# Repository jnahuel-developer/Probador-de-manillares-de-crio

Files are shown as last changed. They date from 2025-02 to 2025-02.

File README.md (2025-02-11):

# 🛠️ Probador de Manillares de Crio  

Dispositivo para probar y validar el correcto funcionamiento de manillares para la terapia de Crio Radio Frecuencia.  
Este repositorio incluye tanto el firmware para el microcontrolador como el diseño del PCB.  

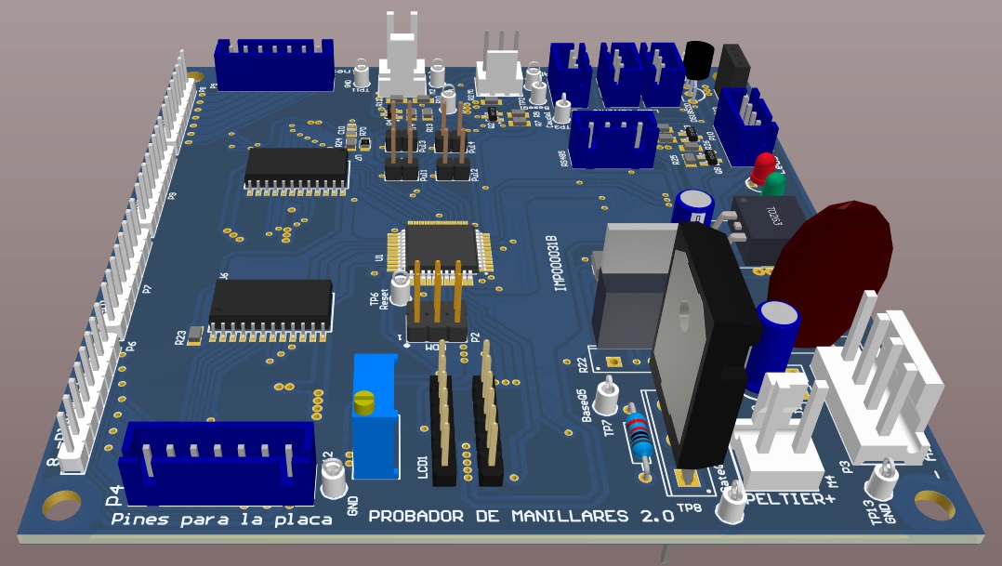
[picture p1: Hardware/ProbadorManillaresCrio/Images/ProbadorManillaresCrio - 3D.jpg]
Vista 3D del PCB
  

---
---

## ❄️ Manillar para la terapia de Crio Radio Frecuencia  

El manillar para la terapia de Crio Radio Frecuencia combina un sistema de refrigeración con un arreglo de terminales para la emisión de RF.  

### 🔹 **Sistema de Refrigeración**  
El sistema de refrigeración incluye una celda Peltier, encargada de disminuir la temperatura sobre los pernos hasta -15°C. Para disipar el calor generado, cuenta con un circuito cerrado de circulación de agua que lo transporta fuera del manillar.  

Para gestionar este proceso, el **Probador** integra:  
- Circuitos independientes de activación de una **bomba de agua de 12V** y un **cooler** de refrigeración del agua.  
- Un **caudalímetro**, que verifica la correcta circulación del flujo de agua.  
- Un **sensor DS18S10**, ubicado en el ingreso de la bomba, que monitorea la temperatura y previene condiciones inseguras.  
- Un **circuito de alimentación de potencia** para la celda Peltier, con una medición de la corriente consumida mediante una **resistencia Shunt**.  
- **Dos sensores DS18S10** adicionales, que registran la temperatura en ambas caras de la celda.  

### 🔹 **Emisión de RF**  
Para la verificación de la emisión de radiofrecuencia, el **Probador** emplea dos **multiplexores analógicos de 16 canales**, los cuales permiten inyectar señales y medir la continuidad de los circuitos. Esto posibilita no solo verificar que los pernos tengan continuidad, sino también que estén correctamente ubicados.  

### 🔹 **Interfaz y Control**  
El **Probador** se maneja mediante un sistema de **cuatro pulsadores** y una **pantalla LCD**, que guían al operador durante el proceso de prueba del manillar.  

Este sistema permite realizar un test completo de cada unidad de manera rápida y eficiente, asegurando su correcto funcionamiento sin necesidad de recurrir a equipos comerciales.

---
---

## 📁 Contenido del Repositorio  

📂 **Probador-de-manillares-de-crio/**  
├── 📁 **firmware/** → Código fuente para el microcontrolador  
├── 📁 **hardware/** → Diseño del PCB, esquemáticos y archivos Gerber  
├── 📜 **README.md** → Documentación principal  

---
---

## 🖼️ Modelos 3D diseñados en Altium Designer  

Vista frontal del PCB:  
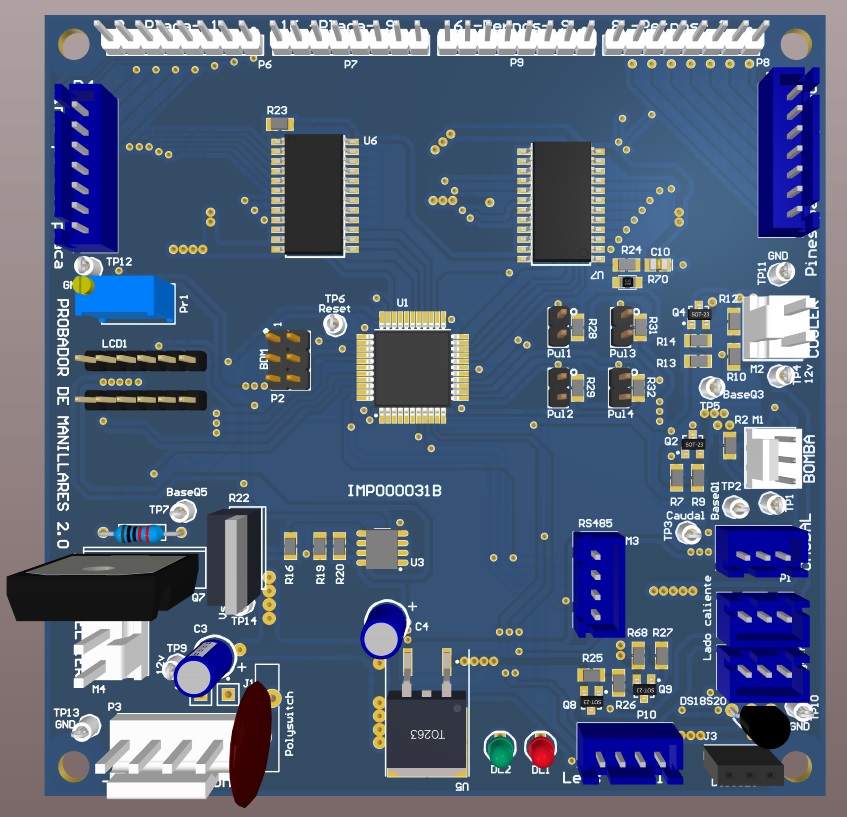
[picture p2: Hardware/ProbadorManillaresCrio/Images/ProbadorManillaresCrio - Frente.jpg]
  

Vista posterior del PCB:  
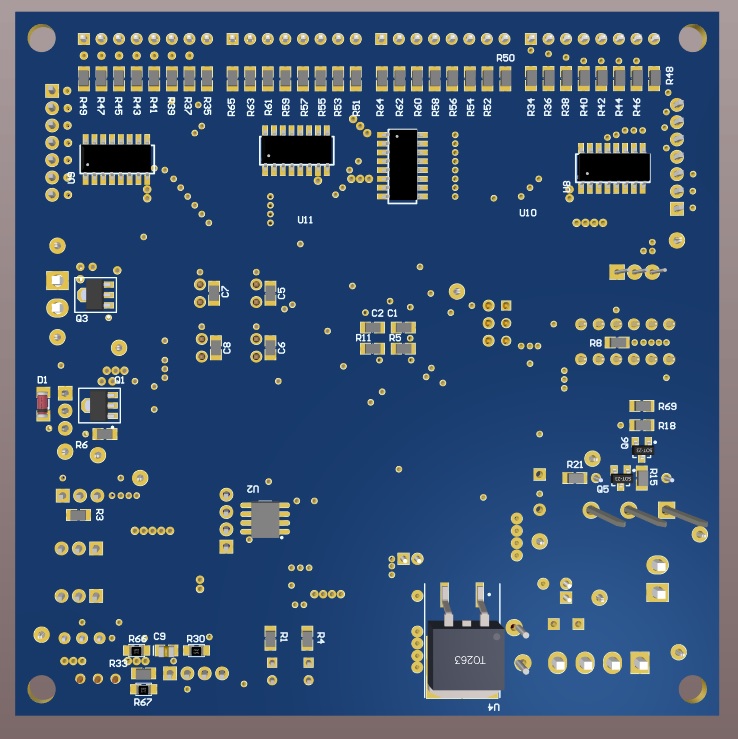
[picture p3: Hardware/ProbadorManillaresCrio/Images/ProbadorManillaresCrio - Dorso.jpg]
  

---
---

## 🛠️ Herramientas Utilizadas  

- **Diseño PCB** → Altium Designer  
- **Modelado 3D** → Altium Designer  
- **Firmware Target** → MC9S08AC16CFD  
- **Compiler** → CodeWarrior HCS08 C Compiler  
- **Lenguaje** → C  

---
---

📩 **Contacto:** [jnahuel.developer@gmail.com](jnahuel.developer@gmail.com)  

📩 **Contacto:** [https://www.linkedin.com/in/jnahuel/](https://www.linkedin.com/in/jnahuel/)

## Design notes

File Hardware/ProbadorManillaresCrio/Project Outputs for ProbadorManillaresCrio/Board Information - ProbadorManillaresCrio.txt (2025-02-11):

Board Information Report
Filename     : \\NAS4FREE\Laboratorio\Dispositivos\Probador de manillares\ProbadorManillaresCrio\ProbadorManillaresCrio.PcbDoc
Date         : 22/11/2018
Time         : 09:39:26 a.m.
Time Elapsed : 00:00:00

General
    Board Size, 4000milsx4000mils
    Components on board, 109
count : 2

Routing Information
    Routing completion, 100,00%
    Connections, 275
    Connections routed, 275
    Connections remaining, 0
count : 4

Layer, Arcs, Pads, Vias, Tracks, Texts, Fills, Regions, ComponentBodies
    Top Layer, 0, 126, 0, 644, 0, 0, 355, 0
    Bottom Layer, 0, 0, 0, 318, 0, 0, 191, 0
    Mechanical 1, 0, 0, 0, 0, 0, 0, 0, 75
    Mechanical 2, 0, 0, 0, 0, 0, 0, 0, 0
    Mechanical 3, 0, 0, 0, 0, 0, 0, 0, 0
    Mechanical 4, 0, 0, 0, 0, 0, 0, 0, 0
    Mechanical 5, 0, 0, 0, 0, 0, 0, 0, 0
    Mechanical 6, 0, 0, 0, 0, 0, 0, 0, 0
    Mechanical 7, 0, 0, 0, 0, 0, 0, 0, 0
    Mechanical 8, 0, 0, 0, 0, 0, 0, 0, 0
    Mechanical 9, 0, 0, 0, 0, 0, 0, 0, 0
    Mechanical 10, 0, 0, 0, 0, 0, 0, 0, 0
    Mechanical 11, 0, 0, 0, 0, 0, 0, 0, 0
    Mechanical 12, 0, 0, 0, 0, 0, 0, 0, 0
    Mechanical 13, 2, 0, 0, 63, 0, 0, 0, 56
    Mechanical 14, 0, 0, 0, 0, 0, 0, 0, 0
    Mechanical 15, 0, 0, 0, 78, 0, 0, 0, 0
    Mechanical 16, 0, 0, 0, 0, 0, 0, 0, 0
    Multi-Layer, 0, 271, 43, 0, 0, 0, 1, 0
    Top Paste, 0, 0, 0, 0, 0, 0, 0, 0
    Top Overlay, 54, 0, 0, 423, 242, 2, 0, 0
    Top Solder, 0, 0, 0, 0, 0, 0, 0, 0
    Bottom Solder, 0, 0, 0, 0, 0, 0, 0, 0
    Bottom Overlay, 0, 0, 0, 0, 0, 0, 0, 0
    Bottom Paste, 0, 0, 0, 0, 0, 0, 0, 0
    Drill Guide, 0, 0, 0, 0, 0, 0, 0, 0
    Keep-Out Layer, 3, 0, 0, 0, 0, 0, 0, 0
    Drill Drawing, 0, 0, 0, 0, 0, 0, 0, 0
count : 28

Layer Pairs, Vias
    Top Layer - Bottom Layer, 43
count : 1

Non-Plated Hole Size, Pads, Vias
count : 0

Plated Hole Size, Pads, Vias
    0mils, 126, 0
    20mils, 0, 41
    32mils, 117, 2
    35mils, 36, 0
    35.433mils, 2, 0
    39.37mils, 8, 0
    39.37mils, 31, 0
    40mils, 59, 0
    55mils, 3, 0
    70mils, 8, 0
    98.5mils, 3, 0
    160mils, 4, 0
count : 12

Non-Plated Slot Size / Length, Pads
count : 0

Plated Slot Size / Length, Pads
count : 0

Non-Plated Square Hole Size, Pads
count : 0

Plated Square Hole Size, Pads
count : 0

Top Layer Annular Ring Size, Count
    -100mils, 4
    -98.5mils, 3
    8mils, 3
    10mils, 3
    18mils, 113
    20mils, 76
    23.622mils, 10
    25mils, 32
    27mils, 4
    30mils, 8
    31.496mils, 31
    35mils, 6
    40mils, 2
    45mils, 14
    48mils, 3
    50mils, 2
count : 16

Mid Layer Annular Ring Size, Count
    -100mils, 4
    -98.5mils, 3
    8mils, 3
    10mils, 3
    18mils, 113
    20mils, 76
    23.622mils, 10
    25mils, 32
    27mils, 4
    30mils, 8
    31.496mils, 31
    35mils, 6
    40mils, 2
    45mils, 14
    48mils, 3
    50mils, 2
count : 16

Bottom Layer Annular Ring Size, Count
    -100mils, 4
    -98.5mils, 3
    8mils, 3
    10mils, 3
    18mils, 113
    20mils, 76
    23.622mils, 10
    25mils, 32
    27mils, 4
    30mils, 8
    31.496mils, 31
    35mils, 6
    40mils, 2
    45mils, 14
    48mils, 3
    50mils, 2
count : 16

Pad Solder Mask, Count
    4mils, 397
count : 1

Pad Paste Mask, Count
    0mils, 397
count : 1

Pad Pwr/Gnd Expansion, Count
    20mils, 397
count : 1

Pad Relief Conductor Width, Count
    10mils, 397
count : 1

Pad Relief Air Gap, Count
    10mils, 397
count : 1

Pad Relief Entries, Count
    4, 397
count : 1

Via Solder Mask, Count
    4mils, 43
count : 1

Via Pwr/Gnd Expansion, Count
    20mils, 43
count : 1

Track Width, Count
    3.937mils, 141
    7mils, 6
    7.874mils, 292
    8mils, 44
    10mils, 67
    12mils, 14
    15mils, 210
    20mils, 559
    40mils, 128
    60mils, 49
    160mils, 16
count : 11

Arc Line Width, Count
    3.937mils, 2
    7mils, 14
    7.874mils, 10
    8mils, 2
    9.843mils, 9
    10mils, 21
    20mils, 1
count : 7

Arc Radius, Count
    4.921mils, 9
    5mils, 1
    10mils, 4
    14.142mils, 7
    19.685mils, 2
    20mils, 1
    28.284mils, 2
    55mils, 14
    80mils, 2
    90mils, 2
    100mils, 10
    110mils, 5
count : 12

Arc Degrees, Count
    132, 10
    180, 2
    298, 2
    360, 45
count : 4

Text Height, Count
    50mils, 4
    59.055mils, 18
    60mils, 220
count : 3

Text Width, Count
    5.906mils, 18
    8mils, 6
    10mils, 218
count : 3

Net Track Width, Count
    54463.647mils, 101
count : 1

Net Via Size, Count
    40mils, 101
count : 1

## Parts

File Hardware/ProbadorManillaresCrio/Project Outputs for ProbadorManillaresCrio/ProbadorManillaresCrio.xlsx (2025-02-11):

Quantity | Designator | Value | Cod.Digikey | Description | Comment | Fabricante | Cod.Fabricante | Footprint | 10
5 | C1, C2, C4, C9, C10 | 100nF | 399-1170-1-ND | CAP CER 0.1UF 50V 10% X7R 0805 | 100nF | Kemet | C0805C104K5RACTU | 6-0805_M | 50 | 399-1170-1-ND | C1, C2, C4, C9, C10
1 | C3 | 10nF | 399-1158-1-ND | CAP CER 10000PF 50V 10% X7R 0805 | 10nF | Kemet | C0805C103K5RACTU | 6-0805_M | 10 | 399-1158-1-ND | C3
2 | C5, C6 | 22pF | 399-1113-1-ND | CAP CER 22PF 50V 5% NP0 0805 | 22pF | Kemet | C0805C220J5GACTU | 6-0805_M | 20 | 399-1113-1-ND | C5, C6
1 | C7 | 22uF 25V | 493-1058-ND | CAP ALUM 22UF 20% 25V RADIAL | 22uF 25V | Nichicon | UVR1E220MDD | CAP100RP | 10 | 493-1058-ND | C7
1 | C8 | 22uF 6.3V | 493-12740-1-ND | CAP ALUM 22UF 20% 6.3V RADIAL | 22uF 6.3V | Nichicon | UVR0J220MDD1TD | CAP100RP | 10 | 493-12740-1-ND | C8
1 | D1 | 1N4148 | 1N4148TACT-ND | DIODE GEN PURP 100V 200MA DO35 | 1N4148 | ON Semiconductor | 1N4148TA | Diodo-DO-35 | 10 | 1N4148TACT-ND | D1
1 | DL1 |  | 732-5005-ND | LED RED DIFFUSED 3MM ROUND T/H | Led3mmRojo | Wurth Electronics Inc. | 151031SS04000 | LED-Rojo-3mm | 10 | 732-5005-ND | DL1
1 | DL2 |  | 732-5008-ND | LED GREEN DIFFUSED 3MM ROUND T/H | Led3mmVerde | Wurth Electronics Inc. | 151031VS06000 | LED-Verde-3mm | 10 | 732-5008-ND | DL2
3 | J1, J2, P8 |  | 455-2248-ND | CONN HEADER XH TOP 3POS 2.5MM | Temp1, Temp2, CAUDAL | JST Sales America Inc. | B3B-XH-A(LF)(SN) | B3B-XH-A_3D | 30 | 455-2248-ND | J1, J2, P8
1 | J3 | DS18S20 | DS18S20+-ND | Temperature Sensor Digital, Local -55°C ~ 125°C 8 b TO-92-3 | DS18S20 | Maxim Integrated | DS18S20+ | DS18S20-ZocaloDirecto | 10 | DS18S20+-ND | J3
2 | J4, J5 |  | No aplica - Es una Isla | Socket | Puente para 12V directos |  |  | PIN1 | 10 | NHD-0208BZ-FL-YBW-ND | LCD1
1 | LCD1 |  | NHD-0208BZ-FL-YBW-ND | LCD MOD CHAR 2X8 Y/G TRANSFL | LCD-08x02-2soportes | Newhaven Display Intl | NHD-0208BZ-FL-YBW | LCD-08x02-2soportes | 10 | A19470-ND | M1
1 | LCD20x4 |  |  | Header, 16-Pin | Header 16 |  |  | LCD-20x4-1soporte | 20 | A1971-ND | M2, M3
1 | M1 |  | A19470-ND | CONN HEADER VERT 3POS .100 TIN | BOMBA | TE Connectivity AMP Connectors | 640456-3 | AMP100X3 | 60 | 732-5315-ND | M4, P12, Pul1, Pul2, Pul3, Pul4
2 | M2, M3 | 640445-2 | A1971-ND | CONN HEADER VERT 2POS .156 TIN | COOLER, PELTIER | TE Connectivity AMP Connectors | 640445-2 | 640445-2_3D | 20 | 455-2249-ND | M5, P7
6 | M4, P12, Pul1, Pul2, Pul3, Pul4 |  | 732-5315-ND | CONN HEADER 2 POS 2.54 | Jumper-Simple, LCD SELECT | Wurth Electronics Inc. | 61300211121 | Jumper-Simple | 20 | 455-2252-ND | P1, P2
2 | M5, P7 |  | 455-2249-ND | CONN HEADER XH TOP 4POS 2.5MM | RS485, A leds Manillar | JST Sales America Inc. | B4B-XH-A(LF)(SN) | B4B-XH-A_3D | 40 | 732-5321-ND | P3, P4, P5, P6
2 | P1, P2 |  | 455-2252-ND | CONN HEADER XH TOP 7POS 2.5MM | Pines para la placa, Pines para los pernos | JST Sales America Inc. | B7B-XH-A(LF)(SN) | B7B-XH-A_3D | 10 | 952-2120-ND | P9
4 | P3, P4, P5, P6 |  | 732-5321-ND | Connector Header Through Hole 8 position 0.100" (2.54mm) | Para la pinera externa | Wurth Electronics Inc. | 61300811121 | PinesMacho8 | 10 | A1972-ND | P11
1 | P9 | M20-9980345 | 952-2120-ND | DIL VERTICAL PC TAIL PIN HEADER | BDM | Harwin Inc | M20-9980345 | HDR2X3_3D | 10 | RGEF700HF-ND | Pl1
1 | P11 |  | A1972-ND | CONN HEADER VERT 4POS .156 TIN | Alimentacion | TE Connectivity AMP Connectors | 640445-4 | 640445-4_3D | 10 | 3296W-502LF-ND | Pr1
1 | Pl1 | 16V 7A | RGEF700HF-ND | PTC RESET FUSE 16V 7A RADIAL | 16V 7A | Littelfuse Inc. | RGEF700 | Polyswitch 200mils | 30 | BC638TACT-ND | Q1, Q3, Q5
1 | Pr1 | 5K | 3296W-502LF-ND | TRIMMER 5K OHM 0.5W PC PIN | 5K | Bourns Inc. | 3296W-1-502LF | Preset_Multi_Vert_3D | 50 | BC33725TACT-ND | Q2, Q4, Q6, Q7, Q9
3 | Q1, Q3, Q5 | BC638 | BC638TACT-ND | TRANS PNP 60V 1A TO-92 | BC638 | ON Semiconductor | BC638TA | TO92 | 10 | IRFP7537PBF-ND | Q8
5 | Q2, Q4, Q6, Q7, Q9 | BC337 | BC33725TACT-ND | TRANS NPN 45V 0.8A TO-92 | BC337 | ON Semiconductor | BC33725TA | TO92 | 160 | S10KCACT-ND | R1, R3, R5, R6, R14, R16, R17, R25, R26, R28, R29, R30, R31, R32, R33, R34
1 | Q8 | IRFP7537PBF | IRFP7537PBF-ND | MOSFET N CH 60V 172A TO247 | IRFP7537PBF | Infineon Technologies Americas Corp. | IRFP7537PBF | TO247 | 100 | S1KCACT-ND | R2, R4, R9, R11, R15, R18, R21, R23, R24, R27
16 | R1, R3, R5, R6, R14, R16, R17, R25, R26, R28, R29, R30, R31, R32, R33, R34 | 10K | S10KCACT-ND | Resistencia axial de 0.25W y 400 mils | 10K | Stackpole Electronics Inc. | RNMF14FTC10K0 | Res-Axial-0.4 | 20 | S4.7KCACT-ND | R7, R13
10 | R2, R4, R9, R11, R15, R18, R21, R23, R24, R27 | 1K | S1KCACT-ND | Resistencia axial de 0.25W y 400 mils | 1K | Stackpole Electronics Inc. | RNMF14FTC1K00 | Res-Axial-0.4 | 10 | S27CACT-ND | R8
2 | R7, R13 | 4.7K | S4.7KCACT-ND | Resistencia axial de 0.25W y 400 mils | 4.7K | Stackpole Electronics Inc. | RNMF14FTC4K70 | Res-Axial-0.4 | 30 | S330CACT-ND | R10, R12, R20
1 | R8 | 27 | S27CACT-ND | Resistencia axial de 0.25W y 400 mils | 27 | Stackpole Electronics Inc. | RNMF14FTC27R0 | Res-Axial-0.4 | 10 | 311-10.0MCRCT-ND | R19
3 | R10, R12, R20 | 330 | S330CACT-ND | Resistencia axial de 0.25W y 400 mils | 330 | Stackpole Electronics Inc. | RNMF14FTC330R | Res-Axial-0.4 | 10 | CF14JT1R00CT-ND | R22
1 | R19 | 10M | 311-10.0MCRCT-ND | RC0805FR-0710ML | 10M | Yageo | RC0805FR-0710ML | 6-0805_M | 10 | 696-1160-ND | R35
1 | R22 | 1 | CF14JT1R00CT-ND | Resistencia axial de 0.25W y 400 mils | 1 | Stackpole Electronics Inc. | CF14JT1R00 | Res-Axial-0.4 | 10 | DS18S20+-ND | Sen1
1 | R35 | 0.05 | 696-1160-ND | 50 mOhms ±5% 35W Through Hole Resistor TO-220-2 Current Sense Thin Film | 0.05 | Riedon | PF2203-0R05J1 | TO-220-Shunt | 140 | 36-5002-ND | TP1, TP2, TP3, TP4, TP5, TP6, TP7, TP8, TP9, TP10, TP11, TP12, TP13, TP14
1 | Sen1 | DS18S20 | DS18S20+-ND | Temperature Sensor Digital, Local -55°C ~ 125°C 8 b TO-92-3 | DS18S20-Soldado | Maxim Integrated | DS18S20+ | TO92-Juntos | 20 | 296-29408-1-ND | U1, U2
14 | TP1, TP2, TP3, TP4, TP5, TP6, TP7, TP8, TP9, TP10, TP11, TP12, TP13, TP14 |  | 36-5002-ND | White PC Test Point, Miniature Phosphor Bronze, Silver Plating 0.040" (1.02mm) Hole Diameter Mounting Type | Test point | Keystone Electronics | 5002 | TP-5002 | 10 | MC9S08AC16CFGE-ND | U3
2 | U1, U2 | CD74HC4067M96 | 296-29408-1-ND | IC MUX/DEMUX 1X16 24SOIC | CD74HC4067M96 | Texas Instruments | CD74HC4067M96 | SOIC24 | 10 | LM340T-12/NOPB-ND | U4
1 | U3 | MC9S08AC16-44 | MC9S08AC16CFGE-ND | S08 S08 Microcontroller IC 8-Bit 40MHz 16KB (16K x 8) FLASH 32-LQFP (7x7) | MC9S08AC16-44 | NXP | MC9S08AC16CFGE | QFP10x10-G44/Z14.4N_3D | 10 | 296-47192-ND | U5
1 | U4 | 7812 | LM340T-12/NOPB-ND | IC REG LINEAR 12V 1A TO220-3 | 7812 | Texas Instruments | LM340T-12/NOPB | TO-220AB | 10 | 296-1275-1-ND | U6
1 | U5 | 7805 | 296-47192-ND | IC REG LINEAR 5V 1A TO220-3 | 7805 | Texas Instruments | LM7805CT/NOPB | TO-220AB | 10 | LM358DR2GOSCT-ND | U7
1 | U6 |  | 296-1275-1-ND | IC TXRX DIFF BUSS 8SOIC | SN7517 |  |  | SN7517 | 10 | CTX914-ND | Y1
1 | U7 |  | LM358DR2GOSCT-ND | Single-Supply Dual Operational Amplifier | LM358DR2 |  |  | 751-07_L
1 | Y1 | 4.9152MHz | CTX914-ND | CRYSTAL 4.9152MHZ 18PF T/H | XTAL_LOW | CTS-Frequency Controls | ATS049B-E | XTAL_LOW

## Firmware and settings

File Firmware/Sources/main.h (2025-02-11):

/* Including needed modules to compile this module/procedure */
#include "Cpu.h"
#include "Events.h"
#include "Vtpm1ovf.h"
/* Include shared modules, which are used for whole project */
#include "PE_Types.h"
#include "PE_Error.h"
#include "PE_Const.h"
#include "IO_Map.h"

/* User includes (#include below this line is not maintained by Processor Expert) */
#include "Display.h"
#include "DS18S20.h"
#include "Timer.h"







		/****************************************************************************************************************/
		/*					  						DEFINICIONES GENERALES												*/
		/****************************************************************************************************************/

	/* Continuidad de los pernos */

#define		MINIMAS_CUENTRAS_PARA_CONTINUIDAD		100
#define		HAY_CONTINUIDAD							TRUE
#define		NO_HAY_CONTINUIDAD						FALSE
#define		TOTAL_DE_CONTACTOS_MULTIPLEXORES		16


// Cantidad de pernos para cada target
#define		TOTAL_DE_PERNOS_MANILLAR_CRIO			7
#define		TOTAL_DE_PERNOS_MANILLAR_ENYGMA			4
#define		TOTAL_DE_PERNOS_CABLE_MAZO_66A			14


// Defines para revisar las posiciones de los pernos segun la rotacion
#define		ROTADO_0_POSICIONES						2
#define		VALOR_J2_ROTADO_0_POSICIONES			2
#define		VALOR_J3_ROTADO_0_POSICIONES			3
#define		VALOR_J4_ROTADO_0_POSICIONES			4
#define		VALOR_J5_ROTADO_0_POSICIONES			5
#define		VALOR_J6_ROTADO_0_POSICIONES			6
#define		VALOR_J7_ROTADO_0_POSICIONES			7

#define		ROTADO_1_POSICIONES						3
#define		VALOR_J2_ROTADO_1_POSICIONES			3
#define		VALOR_J3_ROTADO_1_POSICIONES			4
#define		VALOR_J4_ROTADO_1_POSICIONES			5
#define		VALOR_J5_ROTADO_1_POSICIONES			6
#define		VALOR_J6_ROTADO_1_POSICIONES			7
#define		VALOR_J7_ROTADO_1_POSICIONES			2

#define		ROTADO_2_POSICIONES						4
#define		VALOR_J2_ROTADO_2_POSICIONES			4
#define		VALOR_J3_ROTADO_2_POSICIONES			5
#define		VALOR_J4_ROTADO_2_POSICIONES			6
#define		VALOR_J5_ROTADO_2_POSICIONES			7
#define		VALOR_J6_ROTADO_2_POSICIONES			2
#define		VALOR_J7_ROTADO_2_POSICIONES			3

#define		ROTADO_3_POSICIONES						5
#define		VALOR_J2_ROTADO_3_POSICIONES			5
#define		VALOR_J3_ROTADO_3_POSICIONES			6
#define		VALOR_J4_ROTADO_3_POSICIONES			7
#define		VALOR_J5_ROTADO_3_POSICIONES			2
#define		VALOR_J6_ROTADO_3_POSICIONES			3
#define		VALOR_J7_ROTADO_3_POSICIONES			4

#define		ROTADO_4_POSICIONES						6
#define		VALOR_J2_ROTADO_4_POSICIONES			6
#define		VALOR_J3_ROTADO_4_POSICIONES			7
#define		VALOR_J4_ROTADO_4_POSICIONES			2
#define		VALOR_J5_ROTADO_4_POSICIONES			3
#define		VALOR_J6_ROTADO_4_POSICIONES			4
#define		VALOR_J7_ROTADO_4_POSICIONES			5

#define		ROTADO_5_POSICIONES						7
#define		VALOR_J2_ROTADO_5_POSICIONES			7
#define		VALOR_J3_ROTADO_5_POSICIONES			2
#define		VALOR_J4_ROTADO_5_POSICIONES			3
#define		VALOR_J5_ROTADO_5_POSICIONES			4
#define		VALOR_J6_ROTADO_5_POSICIONES			5
#define		VALOR_J7_ROTADO_5_POSICIONES			6

#define		INVERTIDO_J1_J2							1
#define		VALOR_J1_ROTADO_X_POSICIONES			1

#define		UBICACION_CONTACTO_CARCAZA				7


	/* Peltier */

#define		MAXIMAS_CUENTRAS_PARA_PELTIER			205			// Minima tension que se puede leer y representa un sobre consumo 
#define		MINIMAS_CUENTAS_PELTIER_ENCENDIDA		10
#define		MEDICIONES_PELTIER						65
#define		MEDICIONES_PELTIER_CON_RECIRCULACION	31
#define		MINUTOS_PELTIER_CON_RECIRCULACION		32
#define		TEMPERATURA_MINIMA_PELTIER_INVERTIDA	-20
#define		TEMPERATURA_MINIMA_PELTIER_APAGADA		10
#define		RESOLUCION_MA_PELTIER					33


	/* LEDs */

#define		MINIMAS_CUENTRAS_LEDS_2_RAMAS			36
#define		MINIMAS_CUENTRAS_LEDS_1_RAMA			MINIMAS_CUENTRAS_LEDS_2_RAMAS / 2


	/* Teclas */

#define		MINIMO_DE_OPRESIONES_CUALQUIER_TECLA	5
#define		MINIMO_DE_VECES_SIN_REVISAR_OPRESION	20


	/* Comunicacion serie */

#define		COMUNICACION_HEADER_INICIAL_PRUEBA_REDUCIDA		0xAA
#define		COMUNICACION_HEADER_INICIAL_PRUEBA_COMPLETA		0xEE
#define		COMUNICACION_HEADER_FINAL						0x55
#define		BYTES_TRAMA_PRUEBA_COMPLETA						12
#define		BYTES_TRAMA_PRUEBA_REDUCIDA						10





		/****************************************************************************************************************/
		/*			  						DEFINICIONES DE NUEVOS OBJETOS Y DATOS										*/
		/****************************************************************************************************************/

// Definicion de los estados de la maquina de menues
typedef enum estadosFunciones {
	SIN_PRUEBAS = 0,
	SENSORES_DE_TEMPERATURA_AGREGAR,
	SENSORES_DE_TEMPERATURA_QUITAR,
	SENSORES_DE_TEMPERATURA_MOSTRAR_EXTRA,
	SENSORES_DE_TEMPERATURA_MOSTRAR_CONECTADOS,
	PRUEBA_CRIO_REDUCIDA,
	PRUEBA_CRIO_COMPLETA
};

// Definicion para interpretar mas facilmente los errores de los pernos
typedef enum erroresPernos {
	PERNO_SIN_ERRORES = 0,
	PERNO_ABIERTO,
	PERNO_CORTO_CIRCUITO,
	PERNO_CORTO_CIRCUITO_CARCAZA,
	PERNO_SIN_ALTERNANCIA,
	PERNO_CORTOCIRCUITO_CON_5V
} resultadoPernos;
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

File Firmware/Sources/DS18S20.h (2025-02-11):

/****************************************************************************************************/
/****************************************************************************************************/
/* 						DEFINICIONES PARA MANEJAR LOS SENSORES DE TEMPERATURA 						*/
/****************************************************************************************************/
/****************************************************************************************************/

// Includes
#include "IO_Map.h"
#include "PE_Types.h"



// Defines para los sensores que van a ser practicamente fijos en la placa:

	/*********************************************************************/
	/* *** Sensores para la placa de pruebas completas de manillares *** */
	/*********************************************************************/

	// Sensor soldado directamente
	#define	DS18S20_SOLDADO_BYTE_0		0x10
	#define	DS18S20_SOLDADO_BYTE_1		0x0B
	#define	DS18S20_SOLDADO_BYTE_2		0x38
	#define	DS18S20_SOLDADO_BYTE_3		0x5F
	#define	DS18S20_SOLDADO_BYTE_4		0x03
	#define	DS18S20_SOLDADO_BYTE_5		0x08
	#define	DS18S20_SOLDADO_BYTE_6		0x00
	#define	DS18S20_SOLDADO_BYTE_7		0x69

/*
	// Sensor para la manguera
	#define	DS18S20_MANGUERA_BYTE_0		0x10
	#define	DS18S20_MANGUERA_BYTE_1		0x59
	#define	DS18S20_MANGUERA_BYTE_2		0x2D
	#define	DS18S20_MANGUERA_BYTE_3		0x5F
	#define	DS18S20_MANGUERA_BYTE_4		0x03
	#define	DS18S20_MANGUERA_BYTE_5		0x08
	#define	DS18S20_MANGUERA_BYTE_6		0x00
	#define	DS18S20_MANGUERA_BYTE_7		0x87

	// Sensor para el lado caliente del manillar
	#define	DS18S20_LADO_CALIENTE_BYTE_0		0x10
	#define	DS18S20_LADO_CALIENTE_BYTE_1		0x85
	#define	DS18S20_LADO_CALIENTE_BYTE_2		0x4D
	#define	DS18S20_LADO_CALIENTE_BYTE_3		0x5F
	#define	DS18S20_LADO_CALIENTE_BYTE_4		0x03
	#define	DS18S20_LADO_CALIENTE_BYTE_5		0x08
	#define	DS18S20_LADO_CALIENTE_BYTE_6		0x00
	#define	DS18S20_LADO_CALIENTE_BYTE_7		0x2F
*/

	/******************************************************************************************/
	/* *** Sensores para la placa de pruebas reducidas con el display con todos los pines *** */
	/******************************************************************************************/
/*
	// Sensor soldado directamente
	#define	DS18S20_SOLDADO_BYTE_0		0x10
	#define	DS18S20_SOLDADO_BYTE_1		0xBE
	#define	DS18S20_SOLDADO_BYTE_2		0xA2
	#define	DS18S20_SOLDADO_BYTE_3		0x79
	#define	DS18S20_SOLDADO_BYTE_4		0x03
	#define	DS18S20_SOLDADO_BYTE_5		0x08
	#define	DS18S20_SOLDADO_BYTE_6		0x00
	#define	DS18S20_SOLDADO_BYTE_7		0xF6

	// Sensor para la manguera
	#define	DS18S20_MANGUERA_BYTE_0		0x10
	#define	DS18S20_MANGUERA_BYTE_1		0x59
	#define	DS18S20_MANGUERA_BYTE_2		0x2D
	#define	DS18S20_MANGUERA_BYTE_3		0x5F
	#define	DS18S20_MANGUERA_BYTE_4		0x03
	#define	DS18S20_MANGUERA_BYTE_5		0x08
	#define	DS18S20_MANGUERA_BYTE_6		0x00
	#define	DS18S20_MANGUERA_BYTE_7		0x87

	// Sensor para el lado caliente del manillar
	#define	DS18S20_LADO_CALIENTE_BYTE_0		0x10
	#define	DS18S20_LADO_CALIENTE_BYTE_1		0xDD
	#define	DS18S20_LADO_CALIENTE_BYTE_2		0x83
	#define	DS18S20_LADO_CALIENTE_BYTE_3		0x5F
	#define	DS18S20_LADO_CALIENTE_BYTE_4		0x03
	#define	DS18S20_LADO_CALIENTE_BYTE_5		0x08
	#define	DS18S20_LADO_CALIENTE_BYTE_6		0x00
	#define	DS18S20_LADO_CALIENTE_BYTE_7		0x20
*/

	/**************************************************************************************/
	/* *** Sensores para la placa de pruebas reducidas con el display con menos pines *** */
	/**************************************************************************************/
/*
	// Sensor soldado directamente
	#define	DS18S20_SOLDADO_BYTE_0		0x10
	#define	DS18S20_SOLDADO_BYTE_1		0x0E
	#define	DS18S20_SOLDADO_BYTE_2		0xD4
	#define	DS18S20_SOLDADO_BYTE_3		0x7A
	#define	DS18S20_SOLDADO_BYTE_4		0x03
	#define	DS18S20_SOLDADO_BYTE_5		0x08
	#define	DS18S20_SOLDADO_BYTE_6		0x00
	#define	DS18S20_SOLDADO_BYTE_7		0x88
*/
	// Sensor para la manguera
	#define	DS18S20_MANGUERA_BYTE_0		0x10
	#define	DS18S20_MANGUERA_BYTE_1		0x59
	#define	DS18S20_MANGUERA_BYTE_2		0x2D
	#define	DS18S20_MANGUERA_BYTE_3		0x5F
	#define	DS18S20_MANGUERA_BYTE_4		0x03
	#define	DS18S20_MANGUERA_BYTE_5		0x08
	#define	DS18S20_MANGUERA_BYTE_6		0x00
	#define	DS18S20_MANGUERA_BYTE_7		0x87

	// Sensor para el lado caliente del manillar
	#define	DS18S20_LADO_CALIENTE_BYTE_0		0x10
	#define	DS18S20_LADO_CALIENTE_BYTE_1		0x79
	#define	DS18S20_LADO_CALIENTE_BYTE_2		0x80
	#define	DS18S20_LADO_CALIENTE_BYTE_3		0x5F
	#define	DS18S20_LADO_CALIENTE_BYTE_4		0x03
	#define	DS18S20_LADO_CALIENTE_BYTE_5		0x08
	#define	DS18S20_LADO_CALIENTE_BYTE_6		0x00
	#define	DS18S20_LADO_CALIENTE_BYTE_7		0xEE





/* Macros para las demoras */
#define 	DEMORA_1US				asm( nop ); asm( nop ); asm( nop ); asm( nop );
#define 	DEMORA_480US			TPM1CNT = 0;	while( TPM1CNT < 0x01D8 )	{};		// Para el reset
#define 	DEMORA_410US			TPM1CNT = 0;	while( TPM1CNT < 0x0195 )	{};		// Para el reset
#define 	DEMORA_70US				TPM1CNT = 0;	while( TPM1CNT < 0x0041 )	{};		// Para el reset
#define 	DEMORA_10US				TPM1CNT = 0;	while( TPM1CNT < 0x0005 )	{};		// Para escribir un 1
#define 	DEMORA_55US				TPM1CNT = 0;	while( TPM1CNT < 0x0032 )	{};		// Para escribir un 1
#define 	DEMORA_65US				TPM1CNT = 0;	while( TPM1CNT < 0x003C )	{};		// Para escribir un 0
#define 	DEMORA_5US				TPM1CNT = 0;	while( TPM1CNT < 0x0003 )	{};		// Para escribir un 0
#define 	DEMORA_50mS				TPM1CNT = 0;	while( TPM1CNT < 0xC350 )	{};		// Para darle tiempo al sensor a que convierta la temperatura


/* Defines para el sensor */

#define  	DS18S20_DIRECCION		PTFDD_PTFDD0
#define  	DS18S20_PIN				PTFD_PTFD0
#define  	DS18S20_PUERTO			PTFD
#define		DS18S20_MASCARA			PTFD_PTFD0_MASK		// Es para leer solo el pin del sensor
#define		LONGITUD_ROM_BYTES		8
#define		LONGITUD_ROM_BITS		64
#define		LONGITUD_RESPUESTA		9
#define		TEMPERATURA_BYTE_BAJO	0
#define		TEMPERATURA_BYTE_ALTO	1
#define		TOTAL_DE_SENSORES		4
#define		TOTAL_DE_INTENTOS		10
#define		BYTES_TIPO_DE_SENSOR	0

#define		NO_MAS_COLISIONES		0xFF


typedef enum errores {
	SIN_ERROR = 0,
	PULSO_RESET,
	BUS_SIN_SENSORES,
	ORDEN_INCORRECTA,
	SENSOR_INCORRECTO,
	NO_MAS_SENSORES,
	TEMPERATURA_PROHIBIDA
} erroresDS18S20; 

typedef enum ubicacionSensores {
	SENSOR_SOLDADO_EN_PLACA = 0,
	SENSOR_PARA_LADO_CALIENTE,
	SENSOR_PARA_LA_MANGUERA,
	SENSOR_MANILLAR_O_EXTRA
} posicionSensores;

// Definicion de una estructura para manejar mas facilmente a los sensores, como si fuesen un objeto
typedef struct
{
	unsigned char 	ROM[8];
	int16_t			temperatura;	// Se almacena el valor multiplicado por 10, para evitar usar decimales
	bool			usado;
}sensorDS18S20;



/* **** Defines para las instrucciones de comando de los sensores **** */

// Instruccion para iniciar la conversion de temperatura
#define		INSTRUCCION_DS18S20_INICAR_CONVERSION_T			0

// Instruccion para que se identifique un sensor en particular
#define		INSTRUCCION_DS18S20_USAR_ROM_ID					INSTRUCCION_DS18S20_INICAR_CONVERSION_T + 1
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

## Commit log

2025-02-11 Se agrega el código fuente del firmware para el microncontrolador
2025-02-11 Se agregan los archivos de Altium para la creación de los PCBs
    [Microcontrolador.SchDoc, ProbadorManillaresCrio.PrjPcb, ProbadorManillaresCrio.SchDoc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]
2025-02-11 Se genera la descripción del proyecto
    Se explaya la descripción de la partes, del propósito y las ventajas de uso de este proyecto.
2025-02-11 Cambios menores en la visualización
